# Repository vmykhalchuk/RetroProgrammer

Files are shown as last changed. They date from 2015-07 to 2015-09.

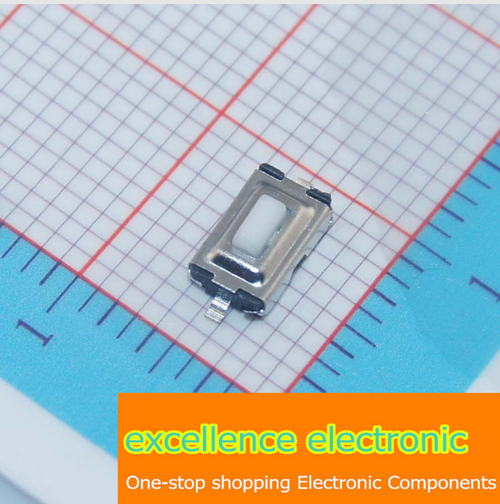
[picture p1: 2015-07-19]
temp/Components/Screen Shot 2015-06-24 at 10.34.04.png

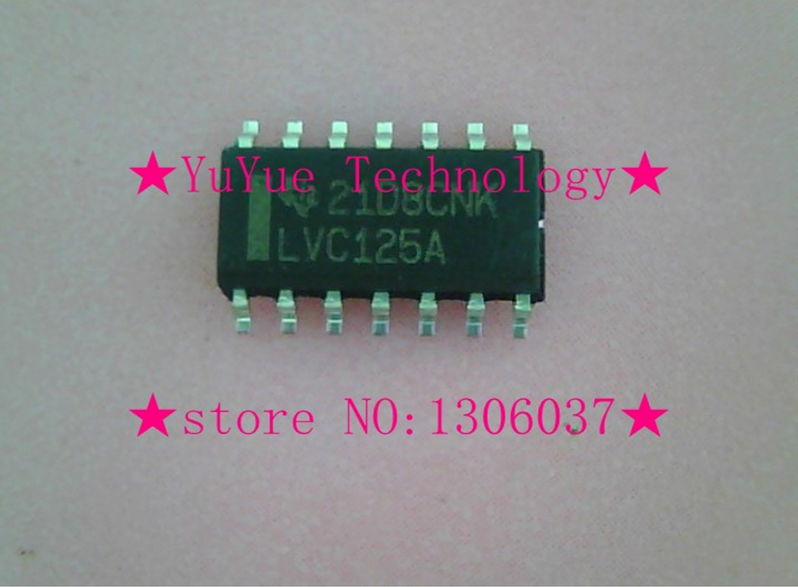
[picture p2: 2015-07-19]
temp/Components/Screen Shot 2015-06-24 at 10.26.43.png

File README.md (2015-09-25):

### Ever wondered what happens when my DIY MCU based device:
* after a years of fruitfull work, something bad happens to MCU?
* or this device gets into hands of other DIY electrician for repairing?
- How then shell I find the binary of firmware used in this particular device?
- Is it located on my hard-drive, or on some of backup CDs, or ... baby elephant know where?
- What if I have many devices or single device with many MCUs, each requiring own firmware?
* Now I have to:
 - find required binaries
 - find proper software to upload it over my Programmer
 - make sure MCU model is same, and proper version of firmware is selected

Well, if this ever bothered you - then Retro Programmer is right for you!

## RetroProgrammer
Board for Arduino Nano to convert Arduino into handheld programmer (SD card support, Target IDentification, no PC required, easy to repeat, cheap)

### Idea behind Retro Programmer
 # Short: You want your DIY project to be repairable by any electrician, without skills in MCUs and deep knowledge of your device? Then Retro Programmer is for you!

 # Long story:
You have this device which you will share with others, or make it for your firends or family.
Still you are wandering, what would they do, if it gets broken, MCU in the device sets on fire or anything else happens that will require MCU to be replaced and firmware uploaded?
Without your help - this device is beyound repair, and your friends cannot just ask any electrician to repair it without having skills uploading frimware to your device.

However there is a solution - meet Retro Programmer!

This super-powerefull and low-cost solution will make it super-easy to upload firmware to your device.
* no need to select type of target MCU
* no need to know which firmware has to be uploaded
* no need to use PC
* no need to install uploader software
* no need to search and download your firmware
* no need to make sure many switches are in right position
* Just SINGLE BUTTON operation
* Is not limited to number of MCUs used in your project or projects

All you need is:
* RetroProgrammer Arduino shield
* Arduino Nano or similar
* MicroSD card
* 1-wire ID Tag or set of resistors (one set for every MCU)

### What is Target IDentification (TID for short)
TID is interface with Target Board to Identify program required to upload to MCU.
TID can be of two types:
* Resistive divider - from 4 to 64 TargetIDs supported
* 1wire ID tag - any number of TaregtIDs

Resistive divider can run over Single or Three lines, each representing values from 0 (not connected), 1 to 4.
If single line is used, then only 4 TargetIDs are supported.
If 3 lines are used, then up to 4x4x4=64 TargetIDs are supported.

However in order to support Any number of TargetIDs, the best choice would be 1wire ID tag.

Thanks to TID, Programmer knows what MCU model is expected on Target board and which program to be uploaded.
This eliminates need in searching for a right firmware, and making sure correct MCU is being used.

### Yes I want it!
* DO NOT! UNDER CONSTRUCTION!!! You can order board from here: http://dirtypcbs.com/view.php?share=9566&accesskey=096bf07bd5bc00aa1c8b3e8581d80cb4
* Components - I might share some in very little quantity
* Firmware - pending... draft version see in sources, feel free to contact me (vmykhalchuk_at_gmail_dot_com) for status
* Manual - describes how to use Retro Programmer and how to prepare your project to be supported by Retro Programmer - pending...

### History
When I was developing smart house solution, main concept that I wanted to build into it was - maintainability.
Maintainability is critical factor of having successful system.
It must be easily repairable without special skills needed.
And since Smart House says by itself - it is smart - so it must use a bunch of different microcontroller units.
The problem with MCUs is that to replace such a component on broken board - you need to have a firmware, pc, knowledge on how to upload new firmware.
This dramatically limits a number of electricians who can service your system.

As a solution, I have designed and developed this Handheld programmer shield for Arduino Nano/Micro.

## Main features
* Fully automated, no PC required to operate
* Autodetection of target MCU (ID of target MCU can be autodetected by using extra pin(s) on ICSP). This lets you UPLOAD programm automatically and in one button press.
* Supports AVR microcontrollers (...TBD...)

## Difference between Board v0.1 and v0.2
* v0.2 board has support for Arduino Micro (A4 and A6 are swapped comparing to v0.1 board).
  This gives possibility to support arduino micro for a sake of lost manual programs choices (not possible to select C,D,3,4), only A,B,1,2 will be active.
* Now it also has fixed pinout of ICSP port (mirrored to represent Socket - not Header on Target board).
  This allows user to attach any other Target device with ICSP header directly to Programmer.

## To be implemented
* Add autocalibration routine to calibrate position of DIP switches
 * add same for LEDs and buttons (in case position of buttons was changed)
* Refactor to support Intel HEX files: https://en.wikipedia.org/wiki/Intel_HEX
* Implement preserving of EEPROM memory when requested in HRP file (otherwise it is erased together with Program memory)
* Implement support of Arduino Bootloader (to avoid erasing whole device)
* CRC every HRP file before programming/verifying it!
 * CRC every conf file
* Auto detection of programming speed
* Auto detection of power present on Target device - to avoid turning programming voltage ON
* Support of 3.3v target MCU
 * How to autodetect if this is 3.3v or 5v device?
 * Then we need level shifter to work on two separate supply levels.
  - For this the ideal solution is: 74LVC2T45; 74LVCH2T45
  - Price on Aliexperess is OK for 50pieces only.
  - Or search for “dual supply level” shifter/translator.
* Extend AVR supported list
* Support PDI interface (http://www.atmel.com/images/doc8282.pdf)
* PIC support
* Support 1-wire EEPROM instead of ID (this will let manufacturer to write version of software required to be uploaded, without need to define every single ID).
 * This is more costly then ID device, however gives more flexibility and allows to support many devices of same type
* USB mode 2: Upload directly from manufacturer web-site (will connect to main website where IDs are registered, and will download program specific for given device).
 * 1-wire eeprom would be beneficial here if manufacturer produced many devices which basically require single version of firmware. So manufacturer can register unique device prototype ID which can be stored on eeprom and uploaded to every such eeprom for every similar device. Then such ID can be used to download firmware required.
* USB mode: Upload to Target MCU from Arduino dev environment via USB cable (no SD involved)
* Add support of ZIF sockets
 * can be implemented as a standalone board connected to ICSP+TD socket
 * there can be also additional DIP switches to select program
 * alternatively mcu with 7segment digits and roller to select program, mcu will have to emulate 1wire interface
* Add two 7segment displays, to monitor status and program selected
* Or add LCD display for this
* Add rotary decoder to quickly select manual programm
* Implement Stack-like error handling with arbitrary data supported for debugging

### To be implemented (DONE)
* Support for Arduino Micro - DONE!!! Board since v0.2 supports Arduino Micro or equivalent.
 * software has to be modified slightly
 * pin A4 must be swapped with A6 (Arduino Micro has no A6 nor A7, so we will have limited Manual programs selection)

## Board improvements / fixes
* Add Atmega directly instead of Arduino Board
* Redesign Controls circuits:
  * Put leds on digital pins instead of analogue
  * Put all buttons on single analogue pin
  * this way we still will use three ports, however:
    # there will be no artifact when led slightly lights when button pressed
    # it will be possible to maintain group of leds ON by using PWM, the brightness will stay same
    # or it will be possible to maintain single led on, however it will light brighter
* Swap UPLOAD <=> BACKUP!!!! This is critical, when ERR led is lit - it reads as UPLOAD button is pressed!
  * Check what happens if other combination of LEDs is lit, which button is then assumed as pressed!
* Add jumper to block Manual program selector - when blocked - only Auto TID is expected to work, otherwise failure!
  - this can be easily done by attaching A3 to ground via jumper, then A3 will read 0, which will indicate program to not read Manual program, and rely on Auto selector only.
* Add jumper to block TargetVPP from being supplied by Programmer
  - this is for precaution, when Target board is externally powered
  - easy to implement by removing jumper which connects D3 to transistor base. When connection is broken, transistor will never open to supply TargetVPP.
  - still MCU can monitor if VPP is provided to MCU by reading voltage on ICSP_VPP directly
* Move LEDs to the edge of board, so they are move visible and distinguishable
* Fix TargetVPP - when Arduino board is not connected, or is RESET - TargetVPP is Enabled till MCU gets control over ports. This must be redesigned! Just remove one transistor, thats it.
* Add LED to show that TargetVPP is ON
* Add switch to turn-off power supply to target MCU (in case it uses own power supply)
  * additionally auto-sense voltage on VPP and disable VPP-on switch to prevent failures
  * also add this option into automatic TargetID detection algorithm - to check if it is expected to have VPP on target board or not, and what level of voltage required (5v or 3.3v)
* Add LED to show when SD card bussy (attach to CS pin)

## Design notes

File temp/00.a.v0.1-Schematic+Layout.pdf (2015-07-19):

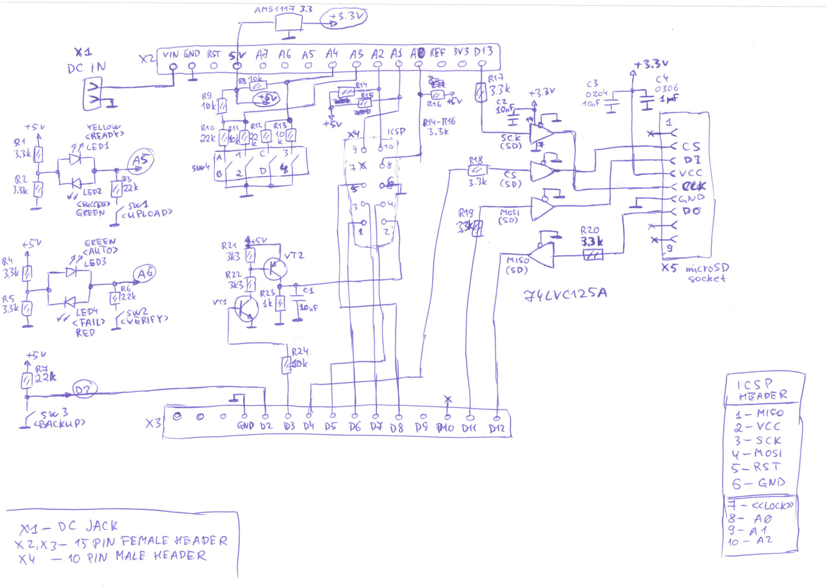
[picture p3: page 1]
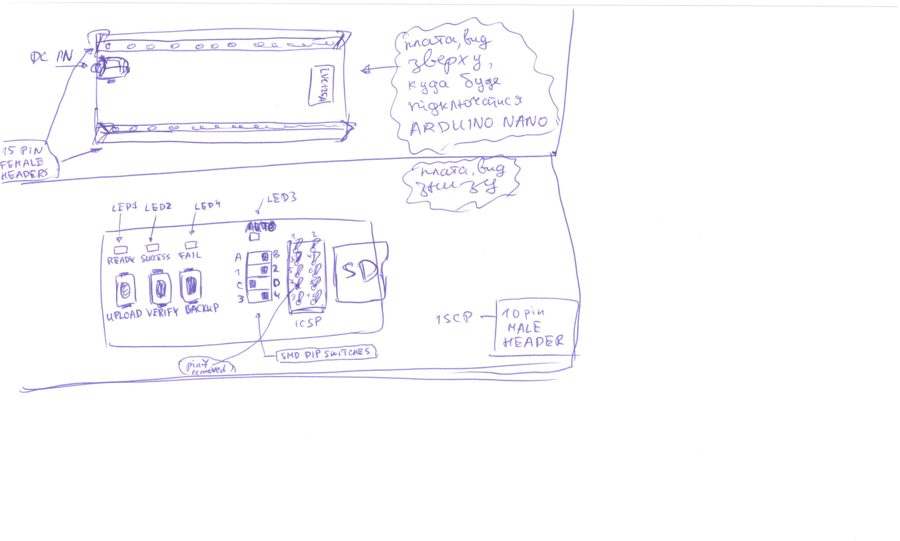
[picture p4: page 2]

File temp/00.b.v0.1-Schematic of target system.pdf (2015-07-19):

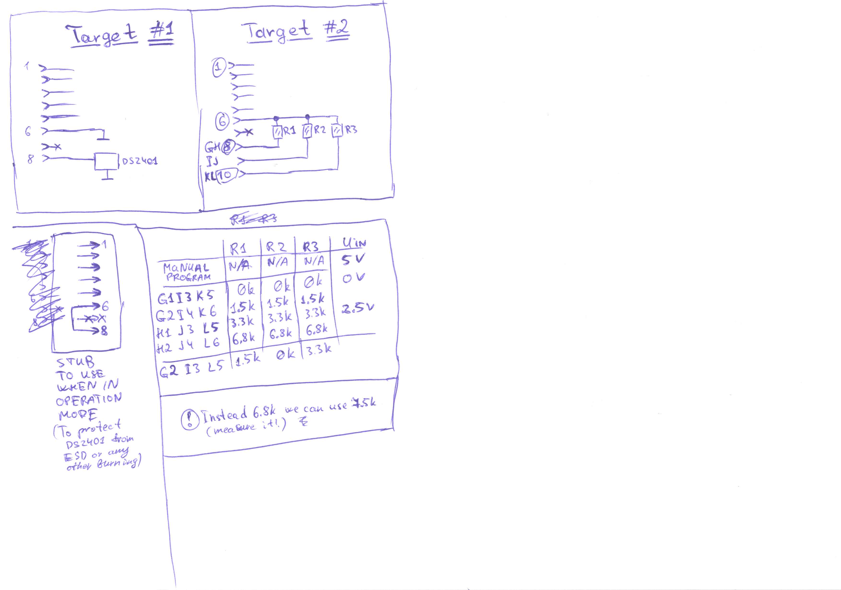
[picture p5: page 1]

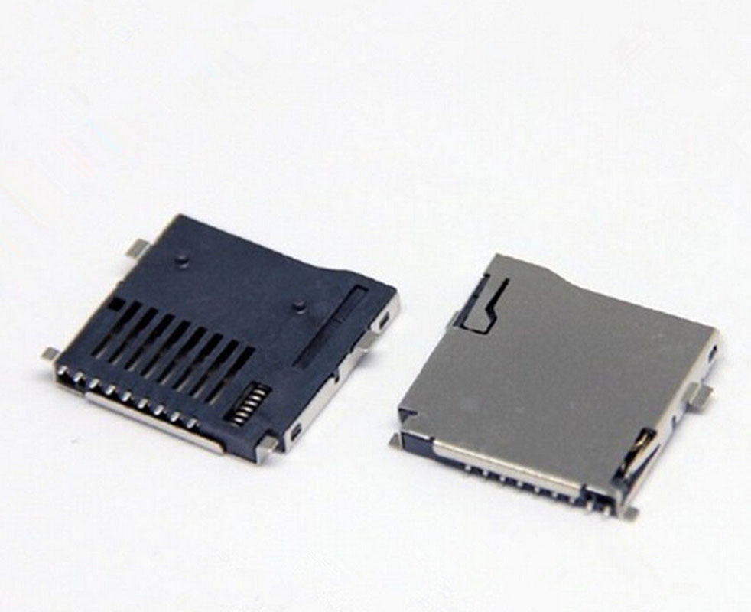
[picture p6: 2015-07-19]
temp/MicroSDSocket/SH-BI-270-MAIN.jpg

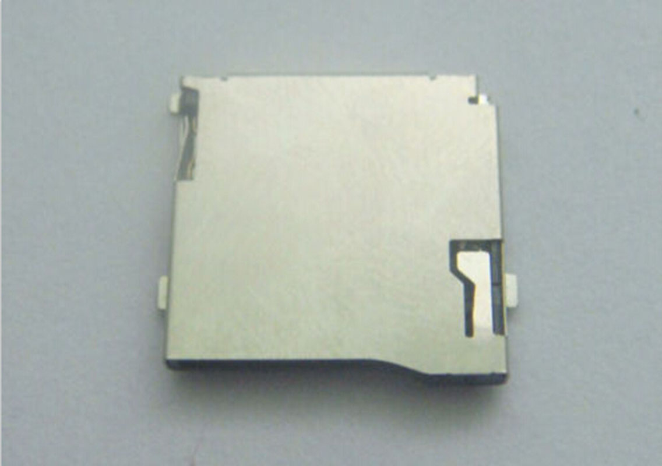
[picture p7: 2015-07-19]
temp/MicroSDSocket/SH-BI-270-MAIN02.jpg

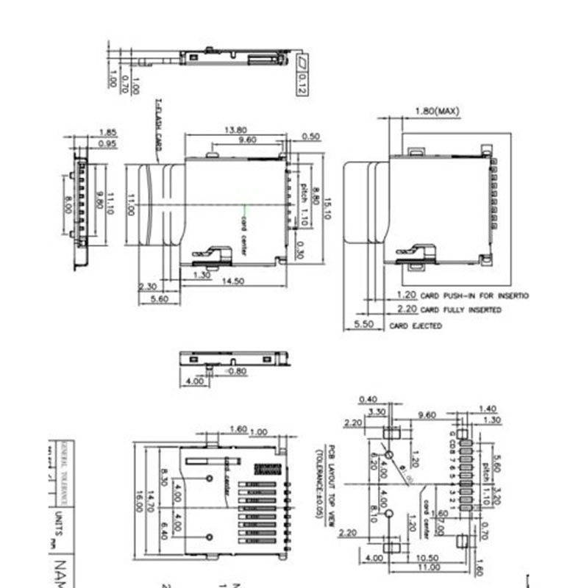
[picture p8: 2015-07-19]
temp/MicroSDSocket/SH-BI-270-MAIN01.jpg

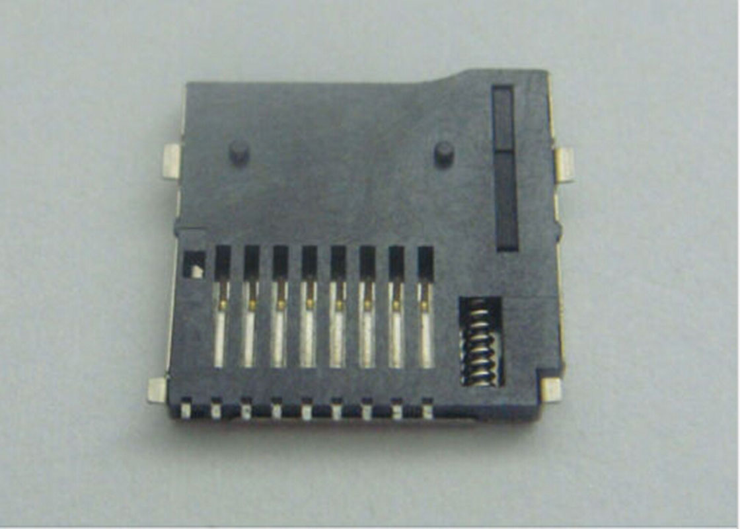
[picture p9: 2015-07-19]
temp/MicroSDSocket/SH-BI-270-MAIN03.jpg

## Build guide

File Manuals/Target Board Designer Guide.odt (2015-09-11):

# How to use TID

In order to benefit from TID, you need to modify Configuration file to map your Program file to the ID received from TID interface.

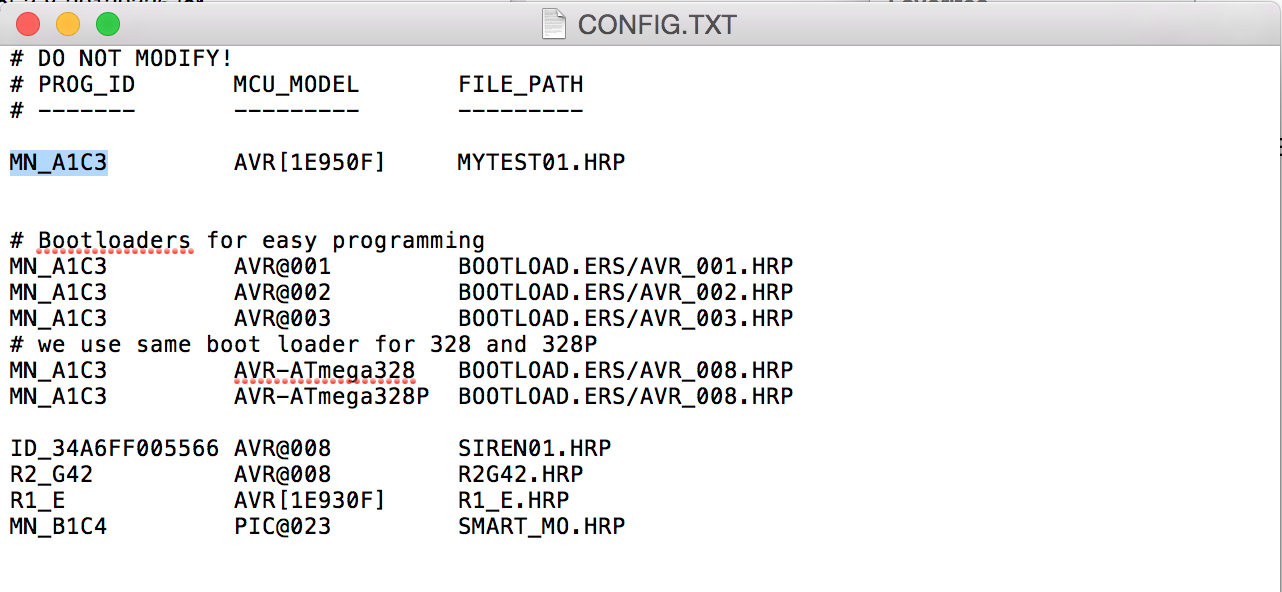
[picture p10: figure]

TID supports two identification methods:

- 1-wire ID Tag
- Resistive dividers

Whichever method you use, will result on Target device ID being generated by Programmer.

TIP: To quickly read TID, run BACKUP of your Target board and see TID stored in backup file:

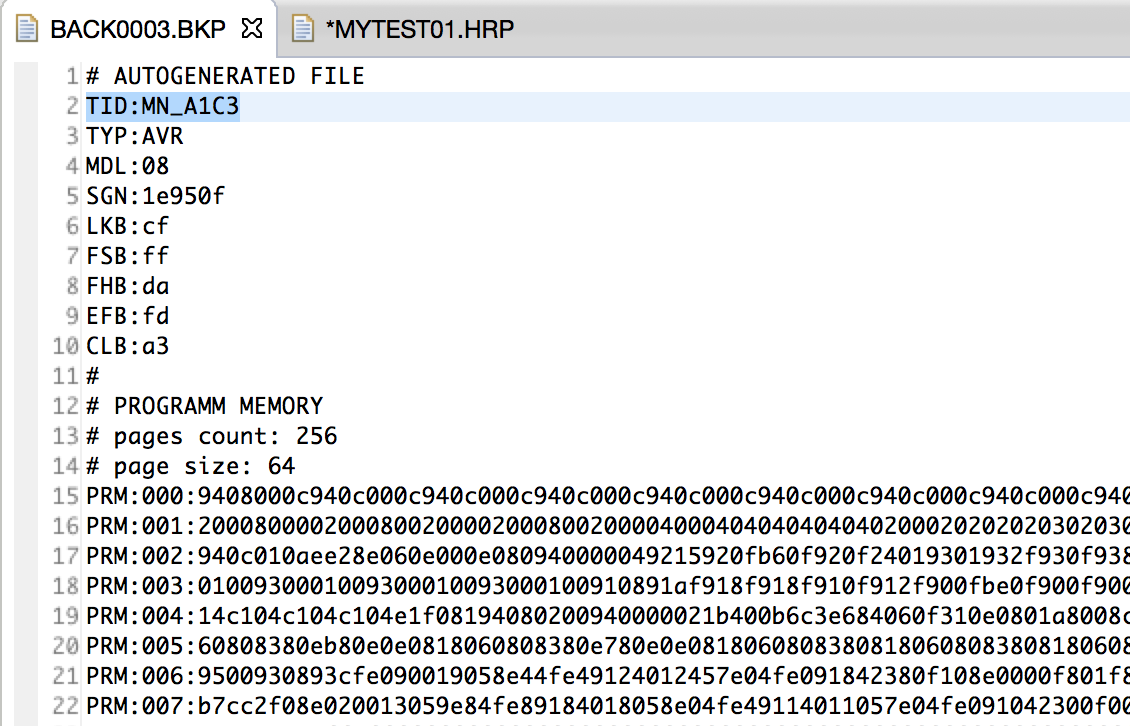
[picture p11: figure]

## 1-wire ID Tag

1-wire ID Tag (DS2401) is connected to GND on ICSP and W0 on TID:

Insert picture here

It generates 48 bits ID, which is then encoded as:

ID_HHHHHHHHHHHH – where HH is a HEX representation of single byte, higher comes first

## Resistive Divider R1

Its possible to use single Resistor to identify Target Board ID, for this resistor with nominal value X has to be attached between W0 and GND.

Resistor value | Target Board ID | User defined Name of program (see CONFIG.TXT)
0k | R1_E
1.5k | R1_F
3.3k | R1_G
6.8k | R1_H

## Resistive Divider R3

Three resistors are attached to ports W0, W1 and W2, same as for R1

Resistor value W0 | Resistor value W1 | Resistor value W2 | Target Board ID | User defined Name of program (see CONFIG.TXT)
0k | 0k | 0k | R3_E11
0k | 0k | 1.5k | R3_E12
0k | 0k | 3.3k | R3_E13
0k | 0k | 6.8k | R3_E14
0k | 1.5k | 0k | R3_E21
0k | 1.5k | 1.5k | R3_E22
0k | 1.5k | 3.3k | R3_E23
0k | 1.5k | 6.8k | R3_E24
0k | 3.3k | 0k | R3_E31
0k | 3.3k | 1.5k | R3_E32
0k | 3.3k | 3.3k | R3_E33
0k | 3.3k | 6.8k | R3_E34
0k | 6.8k | 0k | R3_E41
0k | 6.8k | 1.5k | R3_E42
0k | 6.8k | 3.3k | R3_E43
0k | 6.8k | 6.8k | R3_E44

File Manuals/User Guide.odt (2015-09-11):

# Programming Target MCU

1. Connect ICSP+TID to Target board
2. Connect Power supply to Programmer
3. Reset Arduino board
4. Wait till RDY lights up
5. If AUTO is not lit, select Manual program name using DIP switches. Manual program name is something like A1C3, A2D4, etc
6. Press UPLOAD button => OK led will blink 3 times acknowledging that Upload has started
7. Now RDY will blink showing that Programmer is busy
8. Wait till OK is constantly lit acknowledging that programming finished successfully
9. If ERR is lit, then decipher ERR by counting how many times it blinks. See Appendix A.

# Downloading MCU flash to SD

1. Connect ICSP+TID to Target board
2. Connect Power supply to Programmer
3. Reset Arduino board
4. Wait till RDY lights up
5. Press BACKUP button => OK led will blink once acknowledging that Backup has started
6. Now RDY will blink showing that Programmer is busy
7. Wait till OK is constantly lit acknowledging that backup has finished successfully
8. If ERR is lit, then decipher ERR by counting how many times it blinks. See Appendix A.

# Appendix A

Number of error is displayed via ERR led by blinking it for a number of times:

1. No Target device discovered => make sure ICSP is properly connected
2. SD Card failure => Make sure SD Card is attached, properly formatted and proper files are uploaded
3. Auto Program Identification Failed => Make sure Target board is ICSP+TID compatible, and wires are not too long (no noise on wires)
4. No program file found => Make sure file is available on SD Card & Configuration file is updated with TargetID
5. Wrong Target MCU model => Make sure Conf/Program file is correct and Target MCU resembles expected MCU model
6. Corrupted Program file => Fix it or upload new
7. VERIFY: Program file & Target MCU didn't match => See AUTO for details (press and hold BACKUP button)
8. Target MCU communication failure => Make sure cable is not too long, etc
9. no such error
10. General System Failure => See AUTO for mode details (press and hold BACKUP button)

# Appendix B

In order to define more detail error, press and hold BACKUP button to see secondary error code, which will be displayed by RDY led:

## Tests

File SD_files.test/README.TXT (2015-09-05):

This folder contains test files used to run tests

TEST-01.TXT - example of valid CONFIG.TXT (not true)
TEST-02.TXT - example of wrong CONFIG.TXT (more then once same PROG_ID: MN_A1C3)
TEST-03.TXT - example of wrong CONFIG.TXT (PROG_ID: MN_A1C3 has no DIR_NAME)
TEST-03.TXT - example of wrong CONFIG.TXT (PROG_ID: MN_A1C3 has extra ’s’ character)

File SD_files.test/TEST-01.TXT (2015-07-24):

	   
# comment without no spaces first
  # now comment

R1_E	AVR@002		HJKHJH
MN_A1C3  	BHJGJKG.TTT
  MN_A2C3	HHJ	kjlkjk

 MN_A1C4 BHJGJKG.TTT	 

 R1_E	AVR[1e34f4]		2

#sdfsdfds

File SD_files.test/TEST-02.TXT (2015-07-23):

	   
# comment without no spaces first
  # now comment

# PROG_ID	DIR_NAME
MN_A1C3  	BHJGJKG.TTT
  MN_A2C3	HHJ	kjlkjk

 MN_A1C4 BHJGJKG.TTT	 

MN_A1C3  	d

#sdfsdfds

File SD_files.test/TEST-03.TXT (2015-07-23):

	   
# comment without no spaces first
  # now comment

# PROG_ID	DIR_NAME
MN_A1C3  	

#sdfsdfds

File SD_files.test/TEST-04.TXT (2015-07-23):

	   
# comment without no spaces first
  # now comment

# PROG_ID	DIR_NAME
MN_A1C3s  	WRONG.DIR

#sdfsdfds

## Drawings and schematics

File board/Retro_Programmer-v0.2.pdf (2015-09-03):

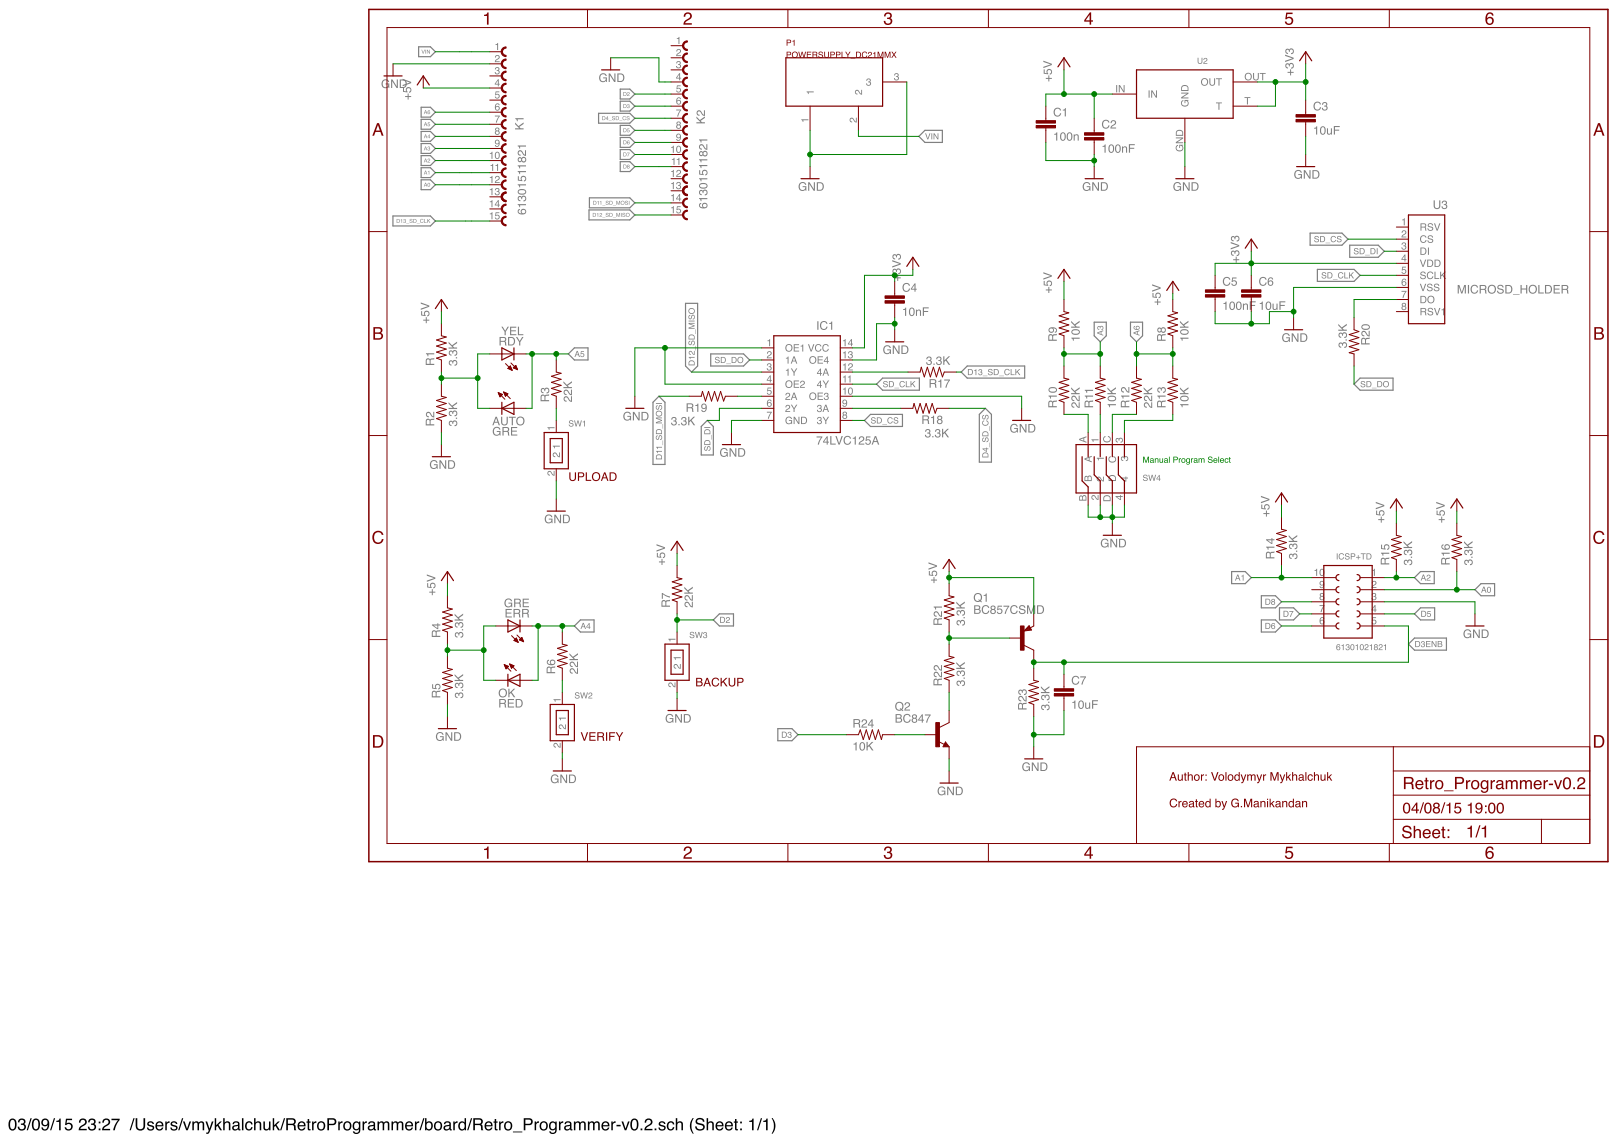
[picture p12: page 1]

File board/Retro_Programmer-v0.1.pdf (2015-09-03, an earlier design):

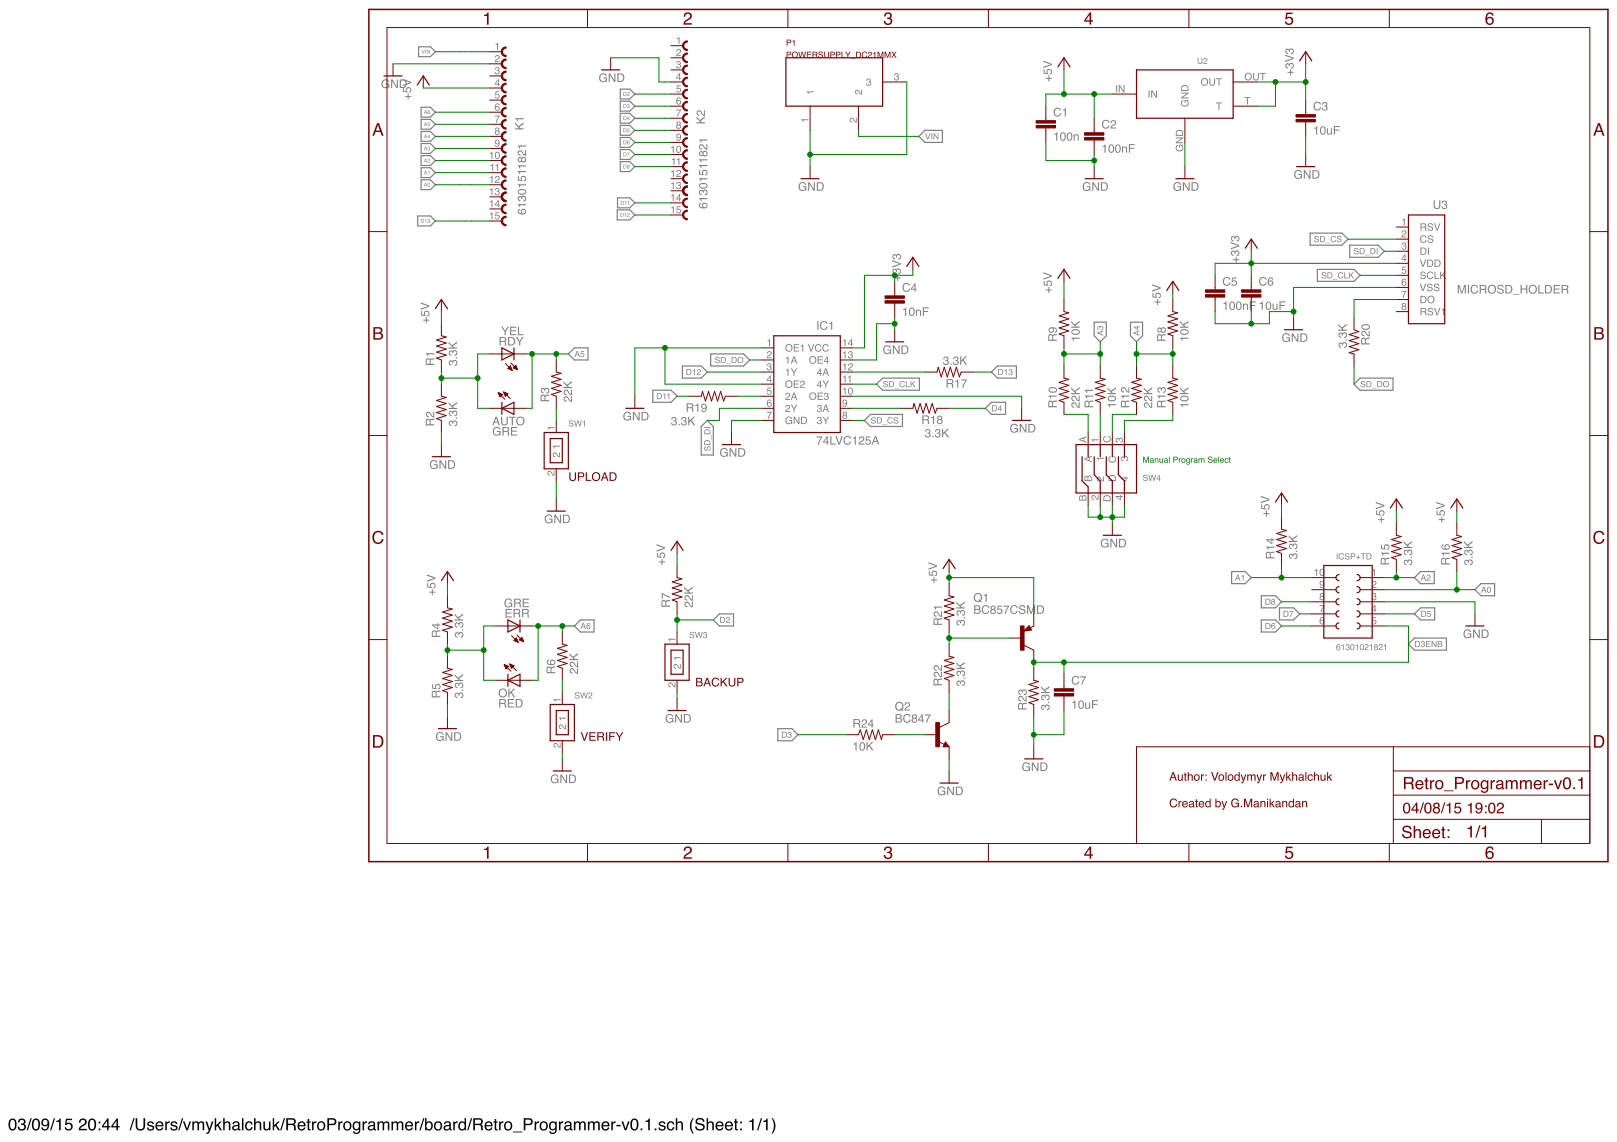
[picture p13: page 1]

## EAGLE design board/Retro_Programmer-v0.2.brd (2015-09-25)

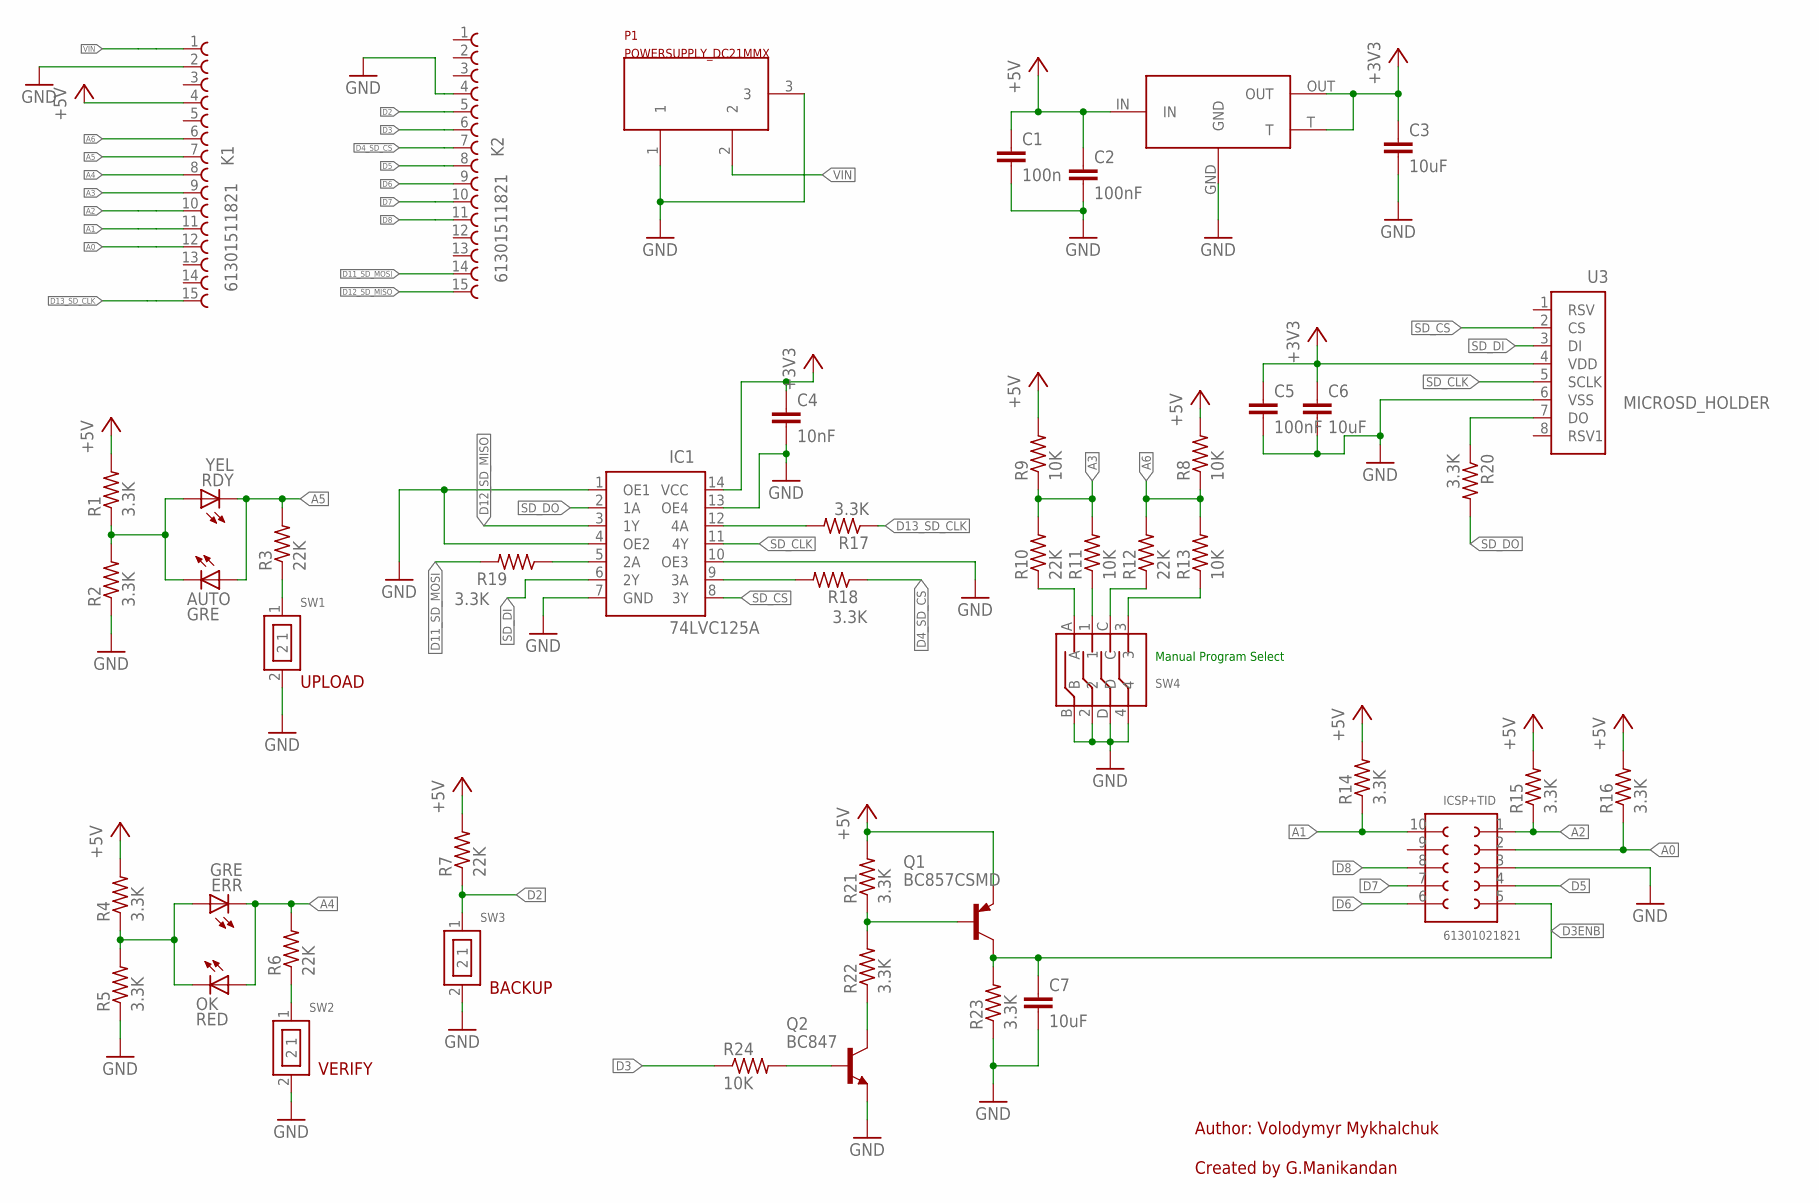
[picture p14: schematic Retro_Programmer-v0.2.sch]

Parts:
AUTO: GRE; CHIPLED_1206
C1: 100n; C1206
C2, C5: 100nF; C1206
C3, C6, C7: 10uF; C1206
C4: 10nF; C1206
ERR: GRE; CHIPLED_1206
IC1: 74LVC125A; SOIC14_74L
ICSP+TID: 61301021821
K1, K2: 61301511821
OK: RED; CHIPLED_1206
P1: POWERSUPPLY_DC21MMX; POWERSUPPLY_DC-21MM
Q1: BC857CSMD; SOT23-BEC
Q2: BC847; SOT23
R1, R2, R4, R5, R14, R15, R16, R17, R18, R19, R20, R21, R22, R23: 3.3K; R1206
R3, R6, R7, R10, R12: 22K; R1206
R8, R9, R11, R13, R24: 10K; R1206
RDY: YEL; CHIPLED_1206
SW1, SW2, SW3: SPUSH; SLIDE1
SW4: SLIDE_WAY4; SLIDESWITCH_4
U2: LT1117; SOT223
U3: MICROSD_HOLDER; SDCARD_HOLDER

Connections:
+3V3: C3.1, C4.1, C5.1, C6.1, IC1.14 (VCC), U2.OUT, U2.T, U3.4 (VDD)
+5V: C1.1, C2.1, K1.4, Q1.E, R1.2, R4.2, R7.2, R8.2, R9.2, R14.2, R15.2, R16.2, R21.2, U2.IN
A0: ICSP+TID.2, K1.12, R16.1
A1: ICSP+TID.10, K1.11, R14.1
A2: ICSP+TID.1, K1.10, R15.1
A3: K1.9, R9.1, R10.2, R11.2
A4: ERR.C, K1.8, OK.A, R6.2
A5: AUTO.A, K1.7, R3.2, RDY.C
A6: K1.6, R8.1, R12.2, R13.2
D2: K2.5, R7.1, SW3.1
D3: K2.6, R24.1
D3ENB: C7.1, ICSP+TID.5, Q1.C, R23.2
D4_SD_CS: K2.7, R18.1
D5: ICSP+TID.4, K2.8
D6: ICSP+TID.6, K2.9
D7: ICSP+TID.7, K2.10
D8: ICSP+TID.8, K2.11
D11_SD_MOSI: K2.14, R19.2
D12_SD_MISO: IC1.3 (1Y), K2.15
D13_SD_CLK: K1.15, R17.1
GND: C1.2, C2.2, C3.2, C4.2, C5.2, C6.2, C7.2, IC1.1 (OE1), IC1.4 (OE2), IC1.7 (GND), IC1.10 (OE3), IC1.13 (OE4), ICSP+TID.3, K1.2, K2.4, P1.1, P1.3, Q2.2 (E), R2.1, R5.1, R23.1, SW1.2, SW2.2, SW3.2, SW4.2, SW4.4, SW4.B, SW4.D, U2.GND, U3.6 (VSS)
unnamed: AUTO.C, R1.1, R2.2, RDY.A
unnamed: R3.1, SW1.1
unnamed: ERR.A, OK.C, R4.1, R5.2
unnamed: R6.1, SW2.1
unnamed: R10.1, SW4.A
unnamed: R11.1, SW4.1
unnamed: R12.1, SW4.C
unnamed: R13.1, SW4.3
unnamed: Q1.B, R21.1, R22.2
unnamed: R20.1, U3.7 (DO)
unnamed: Q2.3 (C), R22.1
unnamed: IC1.12 (4A), R17.2
unnamed: IC1.9 (3A), R18.2
unnamed: Q2.1 (B), R24.2
unnamed: IC1.5 (2A), R19.1
SD_CLK: IC1.11 (4Y), U3.5 (SCLK)
SD_CS: IC1.8 (3Y), U3.2 (CS)
SD_DI: IC1.6 (2Y), U3.3 (DI)
SD_DO: IC1.2 (1A), R20.2
VIN: K1.1, P1.2

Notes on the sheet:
UPLOAD
VERIFY
BACKUP
Created by G.Manikandan
Author: Volodymyr Mykhalchuk
Manual Program Select

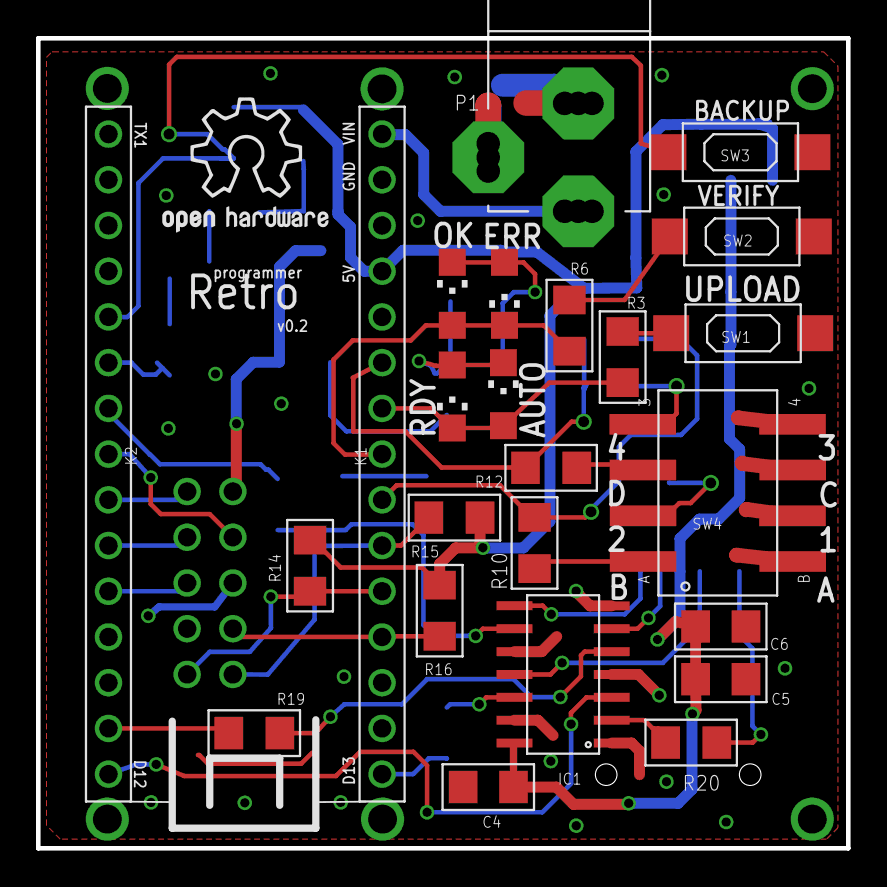
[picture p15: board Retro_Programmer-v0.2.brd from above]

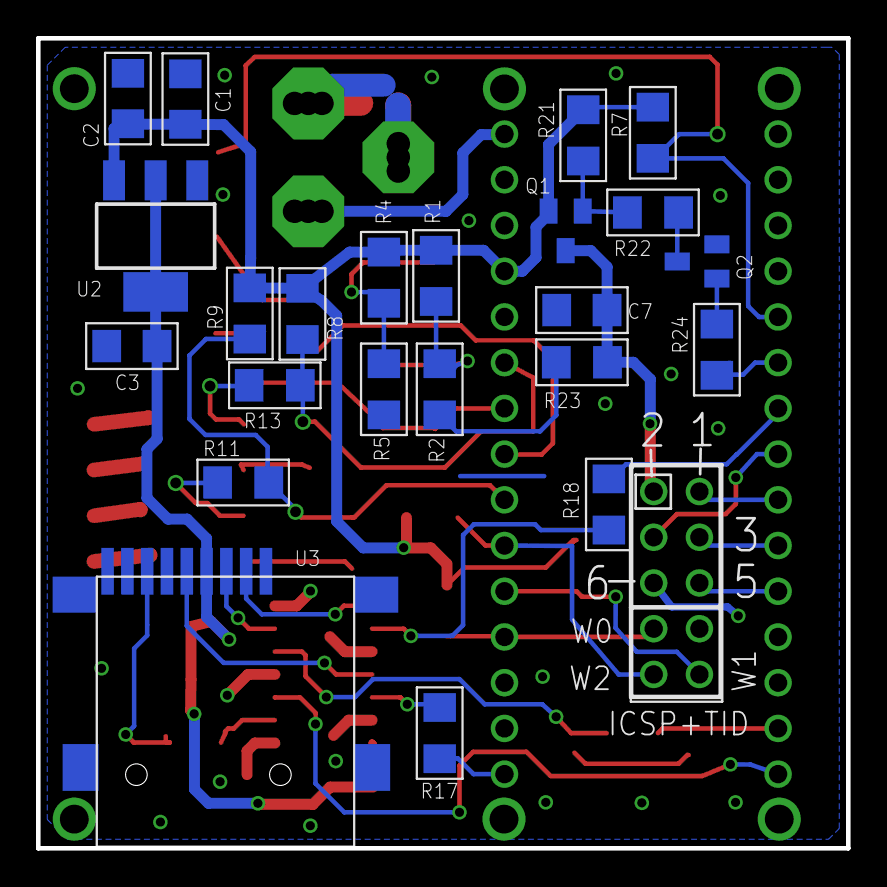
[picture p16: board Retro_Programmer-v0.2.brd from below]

Board: 2 copper layers, 45.0 x 45.0 mm, 48 parts (24 on the bottom side), 41 nets.

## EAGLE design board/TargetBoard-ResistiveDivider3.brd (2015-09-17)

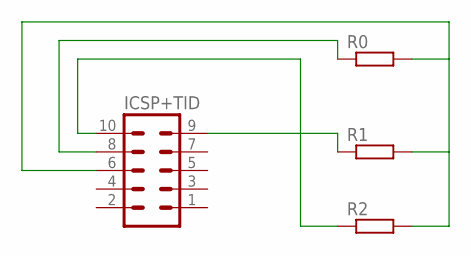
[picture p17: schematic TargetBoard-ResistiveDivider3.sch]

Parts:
ICSP+TID: MA05-2
R0, R1, R2: R-EU_R1206; R1206

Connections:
unnamed: ICSP+TID.6, R0.2, R1.2, R2.2
unnamed: ICSP+TID.8, R0.1
unnamed: ICSP+TID.9, R1.1
unnamed: ICSP+TID.10, R2.1

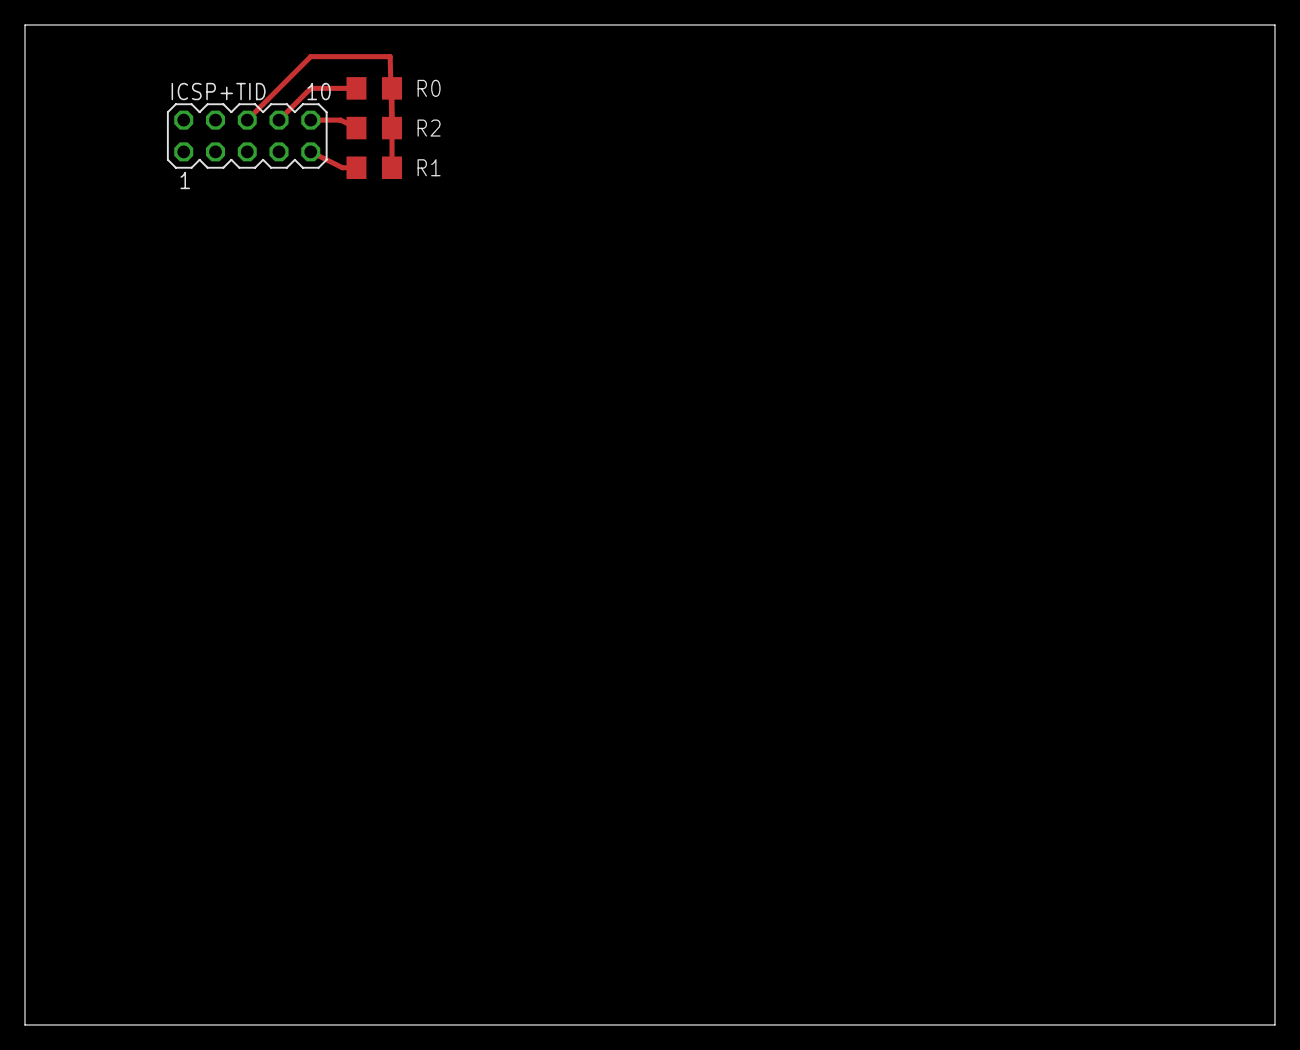
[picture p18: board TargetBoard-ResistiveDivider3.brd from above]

Board: 2 copper layers, 100.0 x 80.0 mm, 4 parts (0 on the bottom side), 4 nets.

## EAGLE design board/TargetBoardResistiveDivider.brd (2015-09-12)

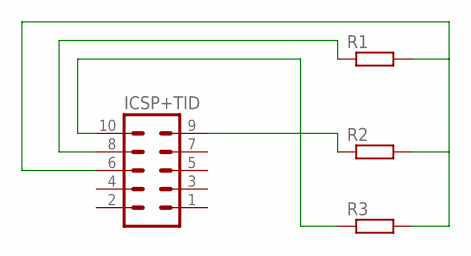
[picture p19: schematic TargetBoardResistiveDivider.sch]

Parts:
ICSP+TID: MA05-2
R1, R2, R3: R-EU_R1206; R1206

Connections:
unnamed: ICSP+TID.6, R1.2, R2.2, R3.2
unnamed: ICSP+TID.8, R1.1
unnamed: ICSP+TID.9, R2.1
unnamed: ICSP+TID.10, R3.1

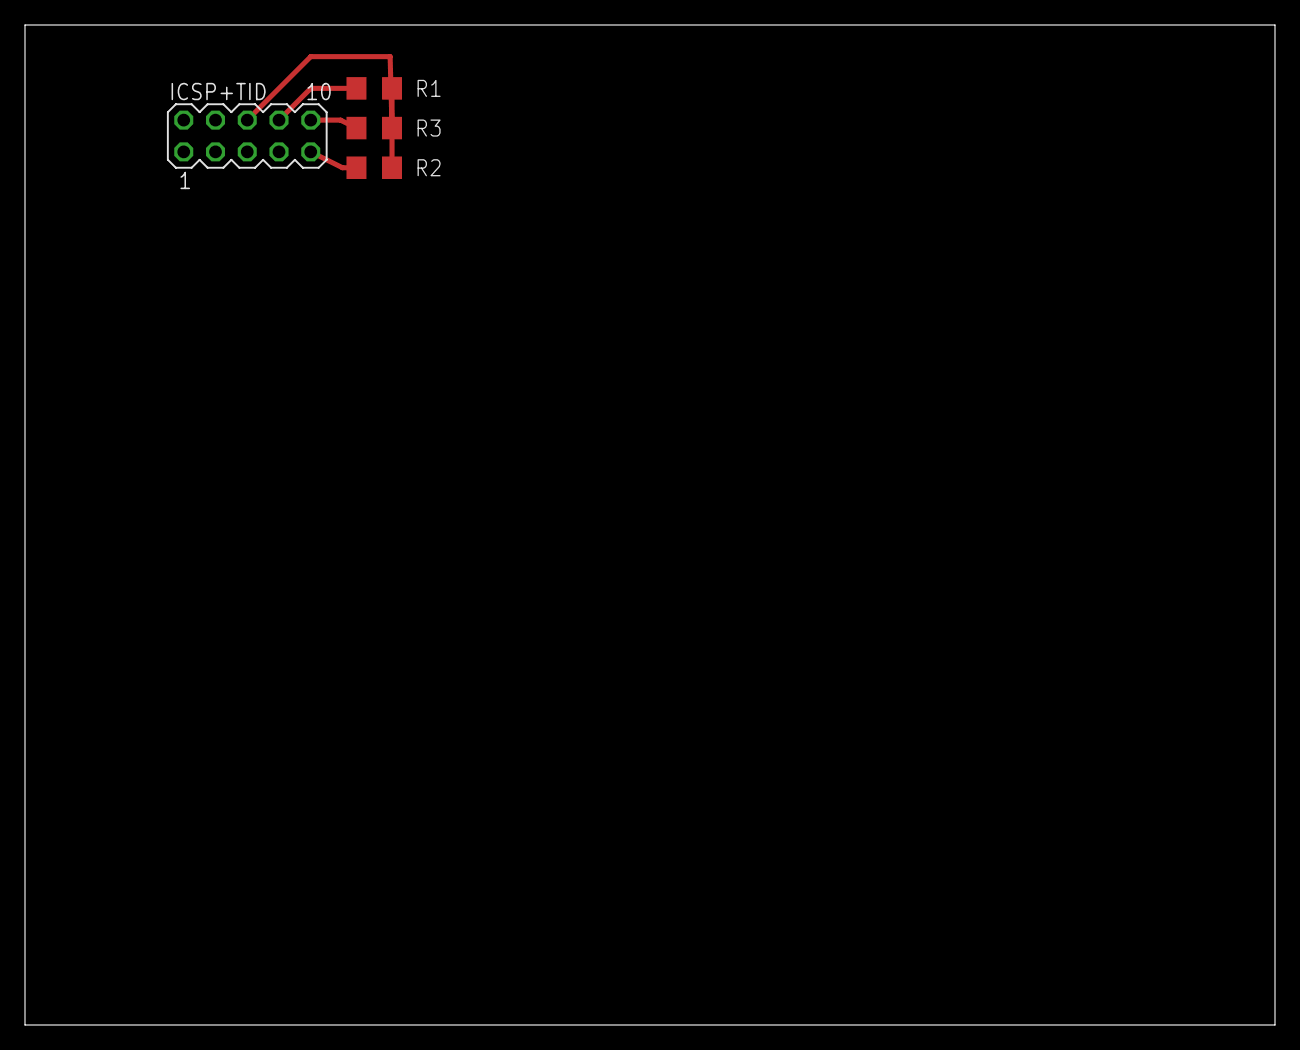
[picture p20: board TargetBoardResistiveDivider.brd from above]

Board: 2 copper layers, 100.0 x 80.0 mm, 4 parts (0 on the bottom side), 4 nets.

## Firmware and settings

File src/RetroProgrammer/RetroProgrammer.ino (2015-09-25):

#include "LoggerA.h"
#include "Statuses.h"
#include "Utils.h"
#include "AVRConstants.h"
#include "AVRProgrammer.h"
#include "ConfFile.h"
#include "HEXFile.h"
#include "ProgramFile.h"
#include "TargetProgramDetector.h"
#include "HWInterface.h"
#include "Tests.h"

#include <SPI.h>
#include <SD.h>

#define ONEWIRE_CRC8_TABLE 0
#include <OneWire.h>

// For Random read
//------------------
//    A7
const byte pinRandomRead = A7;


#define RAM_DEPOSIT_SIZE 55
byte RAM_DEPOSIT[RAM_DEPOSIT_SIZE];

void setup() {
  #if RAM_DEPOSIT_SIZE > 0
    RAM_DEPOSIT[0]=0;
  #endif

  logDebug("Hello World!");

  AVRProgrammer::setup();
  HWInterface::setup();
  //                           TARGET_MCU_ID__W0, TARGET_MCU_ID__W1, TARGET_MCU_ID__W2, TARGET_MCU_ID__MANUAL0, TARGET_MCU_ID__MANUAL1
  TargetProgramDetector::setup(       A0        ,       A1         ,      A2          ,       A3              ,         A6            );
  Logger_setup();


  // TODO:
    // 1) try to upload again and backup and compare BACKUP3 with BACKUP4 (BACKUP4 will be new generated), make sure they match and its not a noise but algorithm issue
    // *) switch logging to 4-DEBUG
    // 2) run setup_tests::Test programming second page of 1blink; see if data is uploaded as expected
  //setup_test();
  setup_prod();
}

void setup_test() {//Used for testing
  byte statusRes=0;
  
  //logFreeRam();

  #if 0
    testUtilsGen();
    testUtilsAVR();
  #endif
  
  #if 0 // Test AVR Signature Read (Target MCU must be connected)
    Tests_AVRProgrammer::testAVRSignatureRead();
  #endif

  #if 0 // Test programming second page of 1blink
                           // Word N Byte Hight | Low:
                           //  W0H   W0L   W1H   W1L   W2H   W2L   W3H   W3L   W4H   W4L   W5H   W5L   W6H   W6L   W7H   W7L
    byte pageToUpload[128] = {0x00, 0x01, 0x02, 0x03, 0x04, 0x05, 0x06, 0x07, 0x08, 0x09, 0x0A, 0x0B, 0x0C, 0x0D, 0x0E, 0x0F, 
                              0x10, 0x11, 0x12, 0x13, 0x14, 0x15, 0x16, 0x17, 0x18, 0x19, 0x1A, 0x1B, 0x1C, 0x1D, 0x1E, 0x1F, 
                              0x20, 0x21, 0x22, 0x23, 0x24, 0x25, 0x26, 0x27, 0x28, 0x29, 0x2A, 0x2B, 0x2C, 0x2D, 0x2E, 0x2F,
                              0x30, 0x31, 0x32, 0x33, 0x34, 0x35, 0x36, 0x37, 0x38, 0x39, 0x3A, 0x3B, 0x3C, 0x3D, 0x3E, 0x3F,
                              0x00, 0x01, 0x02, 0x03, 0x04, 0x05, 0x06, 0x07, 0x08, 0x09, 0x0A, 0x0B, 0x0C, 0x0D, 0x0E, 0x0F, 
                              0x10, 0x11, 0x12, 0x13, 0x14, 0x15, 0x16, 0x17, 0x18, 0x19, 0x1A, 0x1B, 0x1C, 0x1D, 0x1E, 0x1F, 
                              0x20, 0x21, 0x22, 0x23, 0x24, 0x25, 0x26, 0x27, 0x28, 0x29, 0x2A, 0x2B, 0x2C, 0x2D, 0x2E, 0x2F,
                              0x30, 0x31, 0x32, 0x33, 0x34, 0x35, 0x36, 0x37, 0x38, 0x39, 0x3A, 0x3B, 0x3C, 0x3D, 0x3E, 0x3F};
    Tests_AVRProgrammer::testUploadProgramTestPage(MCU_AVR_ATmega328P, 2, pageToUpload, sizeof(pageToUpload));
  #endif

  #if 1 // Test reading Intel HEX file
    Tests_HEXFile::testHEXFile05();
  #endif
  
  #if 0
    Tests_TargetProgramDetector::testTargetProgramDetector();
  #endif

  #if 0 // Upoad test files to SD Card!!!
    // Init SD Card
    if (!UtilsSD::initSDCard()) {
      logError("SD init failed!");
      return;
    }
    Tests_ConfFile::testConfFile();
  #endif

  #if 0 // Test Board ports directly (will lock for indefinite)
    // select only one!
    Tests_Board::testSDCardPorts();
    Tests_Board::testManualProgramSelectorPorts();
  #endif

  #if 0 // Test HWInterface (will lock for indefinite)
    Tests_HWInterface::testLedsAndBtns();
  #endif

  #if 0 // Test Display Error (will lock for indefinite)
    displayError(2, 4, 0);
  #endif

  #if 0 // DO NOT RUN THESE, MAKE SURE THEY ARE SAFE FIRST!
    someOldTests();
  #endif

  logInfo("Happy testing day!");
  logFreeRam();
}

void displayError(byte mainErr, byte subErr, byte okNumber) {
  // Blink ERR mainErr times
  // Blink AUTO subErr times
  //
  // 1 - No Target device discovered => make sure ICSP is properly connected
  // 2 - SD Card failure => Make sure SD Card is attached, properly formatted and proper files are uploaded
  // 2-0 - Not detected => Insert SD Card
  // 2-1 - No Conf file => Make sure Conf file is available on SD card
  // 2-2 - Corrupted Conf file => Check structure, OK display detail of error:
  //           1 - corrupted file, wrong EOL, [0D 0A] sequence is not followed!
  //           2 - unexpected EOL or EOF
  //           3 - too long MCU_MODEL in conf file!
  //           4 - too long FILE_PATH in conf file!
  // 2-3 - Corrupted Program file => Fix it or upload new
  // 2-4 - No space for backups => Remove some backup files to free up space
  // 2-5 - Failure writing Conf file => Make sure SD Card is not corrupted
  // 2-6 - Failure writing Program file => Make sure SD Card is not corrupted
  // 2-7 - Failure opening Program file => Make sure SD Card is not corrupted
  // 2-A - Failure reading file - file format is corrupted
  // 3 - Auto Program Identification Failed => Make sure Target board is ICSP+TID compatible, and wires are not too long (no noise on wires)
  // 3-1 - W1 or W1 wrong ADC value(s)
  // 3-2 - W0 - 1wire CRC didn't match
  // 3-3 -       >>>>
  // 3-4 - failure on the line, too much noise
  // 3-5 -       >>>>
  // 3-6 - W0 - strange state of 1wire device
  // 3-7 - wrong resistive divider value (line unknown)
  // 3-9 - W0 wrong ADC value
  // 3-A - wrong resistive divider value W0
  // 3-B - wrong resistive divider value W1
  // 3-C - wrong resistive divider value W2
  // 4 - No program file found => Make sure file is available on SD Card & Configuration file is updated with TargetID
  // 5 - Wrong Target MCU model => Make sure Conf/Program file is correct and Target MCU resembles expected MCU model
  // 6 - Corrupted Program file => Fix it or upload new
  // 7 - VERIFY: Program file & Target MCU didn't match => See AUTO for details (press and hold BACKUP button)
  // 7-1 - Program EEPROM differs => See OK led for a segment where difference starts
  // 7-2 - Flash EEPROM differs => See OK led for a segment where difference starts
  // 7-3 - Fuse/Lock bits differs => See OK led for which byte differs
  // 8 - Target MCU communication failure => Make sure cable is not too long, etc
  // A - General System Failure => See AUTO for mode details (press and hold BACKUP button)
  // A-1 - Manual Program selector failure
          // ERR(0x68)
  // A-2 - ProgramFile routines error
          // ERR(0x50)
  // A-3 - AVRProgrammer routines error
  // A-4 - Utils routines error
  // A-5 - HWInterface routines error
  // A-6 - ConfFile routines error
  // A-7 - TargetProgramDetector routines error
  // A-0 - Unknown

  while (true) {
    for (int i = 0; i < 20; i++) {
      if (HWInterface::readButtons()) {
        if (i < subErr) {
          HWInterface::setLedOnOff(HWInterface::LED_AUTO, true);
        }
        if (i < okNumber) {
          HWInterface::setLedOnOff(HWInterface::LED_OK, true);
        }
      }
      if (i < mainErr) {
        HWInterface::setLedOnOff(HWInterface::LED_ERR, true);
      }
      
      HWInterface::runLeds(15); // 300ms
      
      HWInterface::setLedOnOff(HWInterface::LED_ERR, false);
      HWInterface::setLedOnOff(HWInterface::LED_AUTO, false);
      HWInterface::setLedOnOff(HWInterface::LED_OK, false);
      
      HWInterface::runLeds(15); // 300ms
    }
  }
}

void confirmProgramSelected(byte btn) {
  byte no = 0;
  if (btn == HWInterface::BTN_UPLOAD) {
    no = 3;
  } else if (btn == HWInterface::BTN_VERIFY) {
    no = 2;
  } else if (btn == HWInterface::BTN_BACKUP) {
    no = 1;
  }
  for (int i = 0; i < no; i++) {
    HWInterface::setLedOnOff(HWInterface::LED_OK, true);
    HWInterface::runLeds(20); // 400ms
    HWInterface::setLedOnOff(HWInterface::LED_OK, false);
    HWInterface::runLeds(20); // 400ms
  }
}

void setup_prod() {
  byte statusRes=0;
  // Init SD Card
  if (!UtilsSD::initSDCard()) {
    logError("SD init failed!");
    displayError(0x2, 0x0, 0x0);
    return;
  }
  
  delay(500);
  HWInterface::setLedOnOff(HWInterface::LED_RDY, true);
  byte btn = HWInterface::waitForUserCommand();
  HWInterface::setLedOnOff(HWInterface::LED_RDY, false);
  logInfoD("Command:",btn);
  delay(500);
  
  // find out what program is selected
  // 3 chars for type (ID_, R1_, R2_, MN_), 12 chars as a max length for ID - 6 bytes, 1 char '/0'
  char progIdBuf[TargetProgramDetector::PROG_ID_BUFFER_SIZE];
  boolean autoSelected;
  TargetProgramDetector::getProgId(progIdBuf, autoSelected, statusRes);
  if (statusRes > 0) {
    logErrorB("getProgId",statusRes);
    byte mainErrCode, subErrCode, okCode;
    TargetProgramDetector::__translateErrorsToDisplayErrorCode(statusRes, mainErrCode, subErrCode, okCode);
    displayError(mainErrCode, subErrCode, okCode);
    return;
  }
  logInfoS("ProgId:", progIdBuf);
  if (autoSelected) {
    HWInterface::setLedOnOff(HWInterface::LED_AUTO, true);
  }
  
  HWInterface::runLeds(25); // 500ms
  confirmProgramSelected(btn);
  HWInterface::runLeds(50); // 1000ms

  // Prepare Target MCU for Programming
  AVRProgrammer::startupTargetMcuProgramming(statusRes);
  if (statusRes > 0) {
    logError("ProgEn failed!");
    AVRProgrammer::shutdownTargetMcu();
    displayError(0x1, 0x0, 0x0);
    return;
  } else {
    logInfo("Started prog!");
  }
  delay(200);

  if (btn == HWInterface::BTN_BACKUP) {
    logInfo("Backup to file...");
    ProgramFile::backupMcuData("BACK", progIdBuf, statusRes);
    if (statusRes > 0) {
      logErrorB("Error backing-up!", statusRes);
      byte mainErrCode, subErrCode, okCode;
      ProgramFile::__translateErrorsToDisplayErrorCode(statusRes, mainErrCode, subErrCode, okCode);
      displayError(mainErrCode, subErrCode, okCode);
      return;
    }
    logInfo("Success backing-up!");
    
  } else if (btn == HWInterface::BTN_VERIFY) {
    logInfo("TESTING!");
    AVRProgrammer::shutdownTargetMcu();
    setup_test();
    logInfo("SUCCESS!");
    
  } else if (btn == HWInterface::BTN_UPLOAD) {
    #if 0
    char mcuModelBuf[UtilsAVR::MCU_MODEL_BUFFER_SIZE];
    char filePath[Utils::FILE_PATH_BUFFER_SIZE];
    byte signBytes[3];
    AVRProgrammer::readSignatureBytes(signBytes, statusRes);
    if (statusRes != 0) {
      logErrorB("readSignError:", statusRes);
      // FIXME displayError! Display correct one!!!!
      displayError(0xA, 0, 0);
    }
    byte mcuModelId = UtilsAVR::getAVRModelIdBySignature(signBytes, statusRes);
    if (statusRes != 0) {
      logErrorB("getModelIdBySign:", statusRes);
      // FIXME displayError! Display correct one!!!!
      displayError(0xA, 0, 0); return;
    }
    logInfoD("AVR MCU ModelId: ", mcuModelId);
    if (!ConfFile::openConfFile("CONFIG.TXT")) {
      logError("No CONFIG.TXT found!");
    }
    boolean detected = ConfFile::getFilePathByProgIdAndMcuModel(progIdBuf, mcuModelId, mcuModelBuf, filePath, statusRes);
    ConfFile::closeConfFile();
    if (statusRes != 0) {
      logErrorB("getProgramFile:", statusRes);
      // FIXME displayError! Display correct one!!!!
      displayError(0xA, 0, 0); return;
    }
    if (!detected) {
      logError("No MCU ProgramFile found!");
      displayError(0x4,0,0); return;
    }
    logInfoS("ProgramFile: ", filePath);
    // Now run Upload process
    ProgramFile::uploadMcuDataFromFile(filePath, mcuModelId, statusRes);
    #endif
  }

  // now shutdown Target MCU
  AVRProgrammer::shutdownTargetMcu();

  logInfo("Done!");
  HWInterface::setLedOnOff(HWInterface::LED_OK, true);
  while (true) {
    HWInterface::runLeds(1);
  }
}

void loop()
{
}

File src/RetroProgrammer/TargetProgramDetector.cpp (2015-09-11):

#include "TargetProgramDetector.h"

// ERR() List:
// 0x60 _ General system error
// 0x69 - failure reading TargetID - _pinW0 wrong ADC value
// 0x61 - failure reading TargetID - _pinW1 or _pinW1 wrong ADC value(s)
// 0x62 - failure reading TargetID - 1wire CRC didn't match
// 0x63 -   >>>>
// 0x64 - failure reading TargetID - failure on the line, too much noise
// 0x65 -   >>>>
// 0x66 - failure reading TargetID - strange state of 1wire device
// 0x67 - failure reading TargetID - wrong resistive divider value (line unknown)
// 0x68 - failure reading Manual Program ID - wrong resistive value (unknown line)
// 0x6A - failure reading TargetID - wrong resistive divider value W0
// 0x6B - failure reading TargetID - wrong resistive divider value W1
// 0x6C - failure reading TargetID - wrong resistive divider value W2

void TargetProgramDetector::__translateErrorsToDisplayErrorCode(byte err, byte& mainErrCode, byte& subErrCode, byte& okCode) {
  mainErrCode = 0;
  subErrCode = 0;
  okCode = 0;
  if (err == 0x60) {
    mainErrCode = 0xA; subErrCode = 0x7;
  } else if (err == 0x68) {
    mainErrCode = 0xA; subErrCode = 0x1;
  } else if (err >= 0x61 && err <= 0x6C) {
    mainErrCode = 0x3; subErrCode = (err & 0xF);
  } else {
    //mainErrCode = 0xA;
    Utils::__translateErrorsToDisplayErrorCode(err, mainErrCode, subErrCode, okCode);
  }
}

byte TargetProgramDetector::_pinW0 = 0;
byte TargetProgramDetector::_pinW1 = 0;
byte TargetProgramDetector::_pinW2 = 0;
byte TargetProgramDetector::_pinManualM0 = 0;
byte TargetProgramDetector::_pinManualM1 = 0;

void TargetProgramDetector::setup(byte pinW0, byte pinW1, byte pinW2, byte pinManualM0, byte pinManualM1)
{
  pinMode(pinW0, INPUT);
  pinMode(pinW1, INPUT);
  pinMode(pinW2, INPUT);
  pinMode(pinManualM0, INPUT);
  pinMode(pinManualM1, INPUT);
  _pinW0 = pinW0;
  _pinW1 = pinW1;
  _pinW2 = pinW2;
  _pinManualM0 = pinManualM0;
  _pinManualM1 = pinManualM1;
}

void TargetProgramDetector::getProgId(char* progId, boolean& autoSelected, byte& statusRes) {
  #if !OPTIMIZE
    initStatus();
  #endif
  autoSelected = true;
  byte id[8];
  byte idType;
  readTargetMcuId(id, idType, statusRes); checkStatus();
  
  byte progIdLength = 3;
  
  if (idType == 0) {
    // Read Manual program (no autodetection)
    autoSelected = false;
    progId[0] = 'M';
    progId[1] = 'N';
    progIdLength += 4;
    readManualProgrammSelector(progId + 3, statusRes);
    #if !OPTIMIZE
      checkStatus();
    #endif
  } else if (idType == 1) {
    // 1Wire ID detected (first 6 bytes of id)
    progId[0] = 'I';
    progId[1] = 'D';
    progIdLength += 12;
    for (byte i = 0; i < 6; i++) {
      progId[3 + i*2] = convertByteToHexChar(id[i + 1], true);
      progId[3 + i*2 + 1] = convertByteToHexChar(id[i + 1], false);
    }
  } else if (idType == 2) {
    // Resistive ID
    progId[0] = 'R';
    progIdLength += 1;
    progId[3] = 'E' + id[0];
    if (id[1] != 127) {
      progId[1] = '1';
    } else {
      progId[1] = '3';
      progIdLength += 2;
      progId[4] = '1' + id[1];
      progId[5] = '1' + id[2];
    }
  }
  progId[2] = '_';
  progId[progIdLength] = '\0';
  return;
}

void TargetProgramDetector::readTargetMcuId(byte* data, byte& idType, byte& statusRes) {
  initStatus();
  int v;

  // Reset ID Chip (or see if W0 is loaded on resistor divider instead)
  pinMode(_pinW0, INPUT);
  delay(1);
  boolean highV = false;
  v = analogRead(_pinW0);
  if (v == 1023) {
    boolean is1wireDevPresent = read1WireId(data, statusRes);
    checkStatus();
    idType = is1wireDevPresent ? 1 : 0;
  } else {
    // most likely it is resistor divider, but check it
    idType = 2;
  }

  if (idType == 0) {
    return;
  } else if (idType == 1) {
    read1WireId(data, statusRes);
  } else { // idType == 2
    // Read Resistive Data
    data[0] = readResistiveDividerValue(_pinW0, statusRes);
    checkOverrideStatus(ERR(0x6A));
    if (data[0] == 127) {
      returnStatus(ERR(0x69)); // failure reading TargetID - _pinW0 wrong value
    }
    data[1] = readResistiveDividerValue(_pinW1, statusRes);
    checkOverrideStatus(ERR(0x6B));
    data[2] = readResistiveDividerValue(_pinW2, statusRes);
    checkOverrideStatus(ERR(0x6C));
    if (data[1] == 127 || data[2] == 127) {
      if (data[1] == 127 && data[2] == 127) {
        // fine, limited version of identification used
      } else {
        returnStatus(ERR(0x61)); // failure reading TargetID - _pinW1 or _pinW1 wrong value(s)
      }
    }
  }
  return;
}

#if USE_ONE_WIRE_LIBRARY
boolean TargetProgramDetector::read1WireId(byte* data, byte& statusRes) {
  initStatus();
  OneWire ds(_pinW0);

  //1-Wire bus reset, needed to start operation on the bus,
  //returns a 1/TRUE if presence pulse detected
  if (ds.reset() != TRUE) {
    return false;
  }
  
  logDebug("- Device present -");
  ds.write(READ_ID_COMMAND);  //Send Read data command
  
  data[0] = (byte) ds.read();
  logDebugB("Family code: ", data[0]);
    
  logDebug("Hex ROM data: ");
  for (byte i = 1; i <= 6; i++) {
    data[i] = (byte) ds.read(); //store each byte in different position in array
    logDebugB("data[]", data[i]);
  }
    
  data[7] = (byte) ds.read(); //read CRC, this is the last byte
  byte crc_calc = OneWire::crc8(data, 7); //calculate CRC of the data

  logDebugB("Calculated CRC: ", crc_calc);
  logDebugB("Actual CRC: ", data[7]);

  if (data[7] != crc_calc) {
    returnStatusV(ERR(0x62), false);
  }
  return true;
}
#else
boolean TargetProgramDetector::read1WireId(byte* data, byte& statusRes) {
  boolean res = reset1Wire(statusRes);
  checkStatusV(false);
  if (!res) {
    return false; // no 1wire device detected
  }
  
  logDebug("- Device present -");
  write1Wire(READ_ID_COMMAND, statusRes);  //Send Read data command
  checkStatusV(false);

  data[0] = read1Wire(statusRes);// Read 1wire device Family code
  checkStatusV(false);
  logDebugB("Family code: ", data[0]);
    
  logDebug("Hex ROM data: ");
  // Read device ID (6 bytes)
  for (byte i = 1; i <= 6; i++) {
    data[i] = read1Wire(statusRes); //store each byte in different position in array
    checkStatusV(false);
    logDebugB("data[]", data[i]);
  }
 
  data[7] = read1Wire(statusRes); //read CRC, this is the last byte
  checkStatusV(false);
  byte crc_calc = OneWire::crc8(data, 7); //calculate CRC of the data

  logDebugB("Calculated CRC: ", crc_calc);
  logDebugB("Actual CRC: ", data[7]);

  if (data[7] != crc_calc) {
    returnStatusV(ERR(0x63), false);
  }
  return true;
}
#endif
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

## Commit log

2015-07-19 Initial design ideas + License
    [config.txt]
2015-07-26 Added schematic and board from Manikandan
    [Retro_Programmer-v0.1.brd, Retro_Programmer-v0.1.sch]
2015-07-26 improved labelling on board
    [Retro_Programmer-v0.1.brd, Retro_Programmer-v0.1.sch]
2015-07-26 font changes
    [Retro_Programmer-v0.1.brd]
2015-07-27 added gerber files
    [Retro_Programmer-v0.1.GBL, Retro_Programmer-v0.1.GBO, Retro_Programmer-v0.1.GBP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]
2015-07-29 More bla bla bla
    [Retro_Programmer-v0.1.brd, Retro_Programmer-v0.1.sch]
2015-08-04 Arduino Sketch for Programmer
    Draft version (not working, only tests)
    [AVRProgrammingRoutines.cpp, AVRProgrammingRoutines.h, RetroProgrammer.ino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]
2015-08-04 Added board v0.2
    v0.2 board has support for Arduino Micro (A4 and A6 are swapped
    comparing to v0.1 board) which gives possibility to support arduino
    micro for a sake of lost manual programs choices (not possible to
    select C,D,3,4), only A,B,1,2 will be active.
    [Retro_Programmer-v0.2.brd, Retro_Programmer-v0.2.sch]
2015-09-03 Fixed HWInterface; Small fixes
    [HWInterface.cpp, RetroProgrammer.ino, TargetProgramDetector.cpp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]
2015-09-03 Mirrored ICSP
    [Retro_Programmer-v0.2.brd]
2015-09-03 Fixed ground connection to ICSP
    [Retro_Programmer-v0.2.brd]
2015-09-05 Improved errors handling, Code refactoring, Organised tests
    [AVRProgrammer.cpp, AVRProgrammer.h, HWInterface.cpp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]
2015-09-05 Board: Fixed ICSP+TID label, and other labels
    [Retro_Programmer-v0.2.brd, Retro_Programmer-v0.2.sch]
2015-09-06 Refactoring; Improved error handling
    [AVRProgrammer.cpp, AVRProgrammer.h, HWInterface.cpp]
2015-09-12 board: improved ICSP marking
    [Retro_Programmer-v0.2.brd, TargetBoardResistiveDivider.brd, TargetBoardResistiveDivider.sch]
2015-09-17 Fixed issue with Upload of HRP file
    - fixed by swapping order of Low & High bytes to be loaded
    - swapped low and high in the file - to match low-endian applied in
    Intel HEX (Arduino)
    - small fixes
    [AVRProgrammer.cpp, AVRProgrammer.h, RetroProgrammer.ino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]
2015-09-17 Added Target board ICSP+TID examples
    [TargetBoard-1wireId.brd, TargetBoard-1wireId.sch, TargetBoard-ResistiveDivider1.brd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]
2015-09-25 Board v0.2 - corrected DIP labels (code correction required)
    [Retro_Programmer-v0.2.brd]

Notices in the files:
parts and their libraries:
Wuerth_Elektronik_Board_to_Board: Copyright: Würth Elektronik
